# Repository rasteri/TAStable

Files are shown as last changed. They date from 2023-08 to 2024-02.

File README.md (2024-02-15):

# TAStable
Deliciously synchronizing the SNES' APU to its CPU clock

## Background
With few exceptions, Tool Assisted Speedruns are rigid lists of controller inputs that have no way to adapt to changing circumstances, and so require the game console to behave in a completely deterministic manner.

Many consoles - ones that drive their logic synchronously from a single master clock - behave more-or-less identically each time they are reset, and so are relatively simple to design speedruns for.

The SNES throws a spanner in the works by having its audio subsystem run from a separate clock. This secondary clock runs completely asynchronously to the main CPU clock, and in fact is derived from a very imprecise source (ceramic resonator). This plus a very non-deterministic reset circuit makes the SNES a difficult moving target for tool assisted speedruns to hit.

Workarounds such as latch trains have been found that increase reliability for certain games, but there are many others which just refuse to sync.

So we decided to just cheat and modify the console instead.

## Theory

NOTE - All of this applies to the 3chip snes (specifically the shvc-cpu-01 with SHVC-sound module) and may or may not be adaptable to other models.

### Terms - 
CPU - the main 65816 processor in the SNES

PPU1/PPU2 - the Picture Processing Units that generate graphics

APU - Audio Processing Unit, actually comprised of two processors - the SMP and DSP.

### Clock Domain Synchronizing

The SNES has two clock domains that are derived from two discrete non-synchronized oscillators. To have a hope of making the SNES deterministic, we have to derive these clocks from a common source.

Clock domain one is derived from a crystal and runs at 21.4773MHz (fraction 945/44). It directly clocks the CPU as well as PPU1 and PPU2.

Clock domain two is derived from a ceramic resonator and runs at 24.576MHz (29×48 kHz). It directly clocks the DSP, which in turn divides it by 12* and clocks the SMP.

*(During startup the DSP actually clocks the SMP at 1.024MHz for a while, presumably to synchronize the DSP and SMP’s memory read cycles, which we’ll go into later)

The ratio of the CPU clock to the APU clock is exactly 39375/45056, but that’s a little tricky to achieve in a low-cost FPGA. However a ratio of 7/8 is easier to implement and is close enough, in fact well within the tolerance of the ceramic resonator, so this ratio was decided upon.

Some simple FPGA code was written to generate a master 171.8184MHz clock. This is then divided by 7 to get a 24.55MHz APU clock, and divided by 8 to get a 21.4773MHz CPU clock.

Just deriving the clocks from a common source was good enough to make at least one game (Donkey Kong Country 2) “deterministic enough” to complete reliably - although it still required other workarounds (latch trains) to compensate for the remaining nondeterminism. Other games (Super Metroid) were still proving impossible to sync, so the decision was taken to track down every other source of nondeterminism come hell or high water.

### Reset Sequencing

The reset arrangement in the SNES looks like this : 

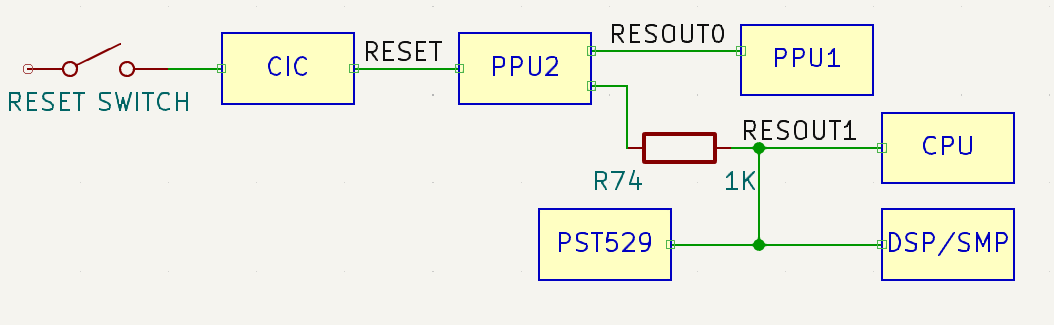
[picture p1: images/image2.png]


Net names are from the “snes_schematic_color.pdf” that’s floating around.

There are a number of ways the SNES can be reset. 

* Turning it on. The CIC will reset the PPU and the PST529 will reset the CPU/DSP/SMP. The PST529 takes a different amount of time to reset each time the SNES is switched on.
* Pressing the reset switch. The CIC will reset PPU2, which will in turn reset all the other components. As the CPU and APU’s resets are connected through a 1K resistor, this causes the signal to rise slowly and thus be susceptible to noise and other factors.
* Pull RESOUT1 low using external circuitry. This is often done to automate TAS playback, as the signal is accessible on the cartridge and expansion ports. This resets the CPU and DSP, but unfortunately doesn’t reset the PPU so leaves it in an unknown state.

None of these approaches allow the reset signal to trigger all ICs simultaneously. Luckily the solution is simple : 

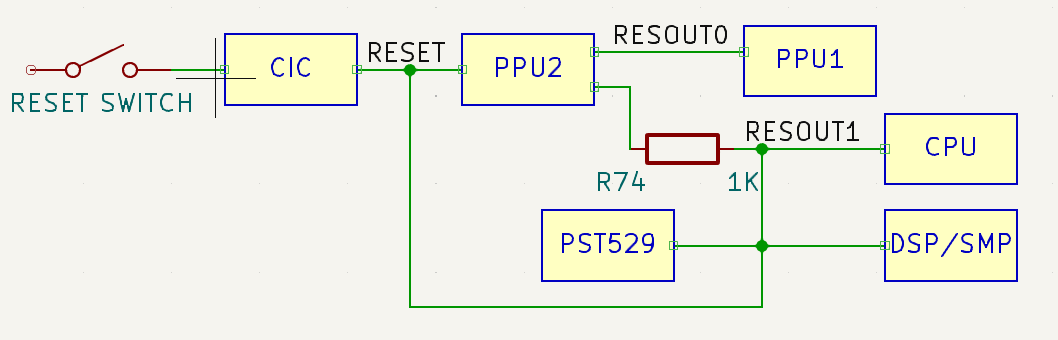
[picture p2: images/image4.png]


If RESOUT1 and RESET are connected together, all ICs are reset simultaneously (or at least, in a repeatable fashion).

There may be a better way to do this (maybe just shorting R74?)

### Reset Timing

This is still not enough to guarantee fully deterministic behavior, as with this setup we aren’t controlling the exact timing of the reset signal itself. Thus, the reset signal might happen at ANY point in the 21MHz/24MHz “synchronization cycle” - and there are infinite possibilities.

The “synchronization cycle” is equivalent to the beat frequency of the two clocks - i.e. 3MHz. So to ensure that the systems start up the same way each time, we have to ensure that the reset signal comes at the same point in the beat frequency on each reset.

To do this we can generate a third clock from the master 171.8184MHz clock, with a divider of 56, and reset the CPU/APU/PPUs on its rising (or falling) edge. As long as all three clocks are kept in the same phase, the reset signal will always happen at the same time in the clock sequence, and should guarantee determinism.

But, infuriatingly, even synchronizing the reset signal to the clock phase still doesn’t make the console 100% deterministic. It lowers the number of “different behaviour patterns” to about 20, so we know we’re going in the right direction, but there is still one more piece of the puzzle.

### Memory Bus Sniffing

The final piece of nondeterminism comes from the APU. As mentioned before, the DSP generates the SMP’s 2MHz clock by dividing the 24MHz clock. Unfortunately, the internal counters that the DSP uses to derive that clock are reset to a random state when the console powers up, and there is (probably?) no way to reset them back to zero. So, we need to find another way to determine where the APU is in its operation cycle.

When the APU starts up, it performs a number of read operations on its memory bus, followed by a memory write. After that point it appears to stabilize, i.e. it behaves deterministically. So if we can delay starting the CPU until after the first APU memory write, this will synchronize the two:

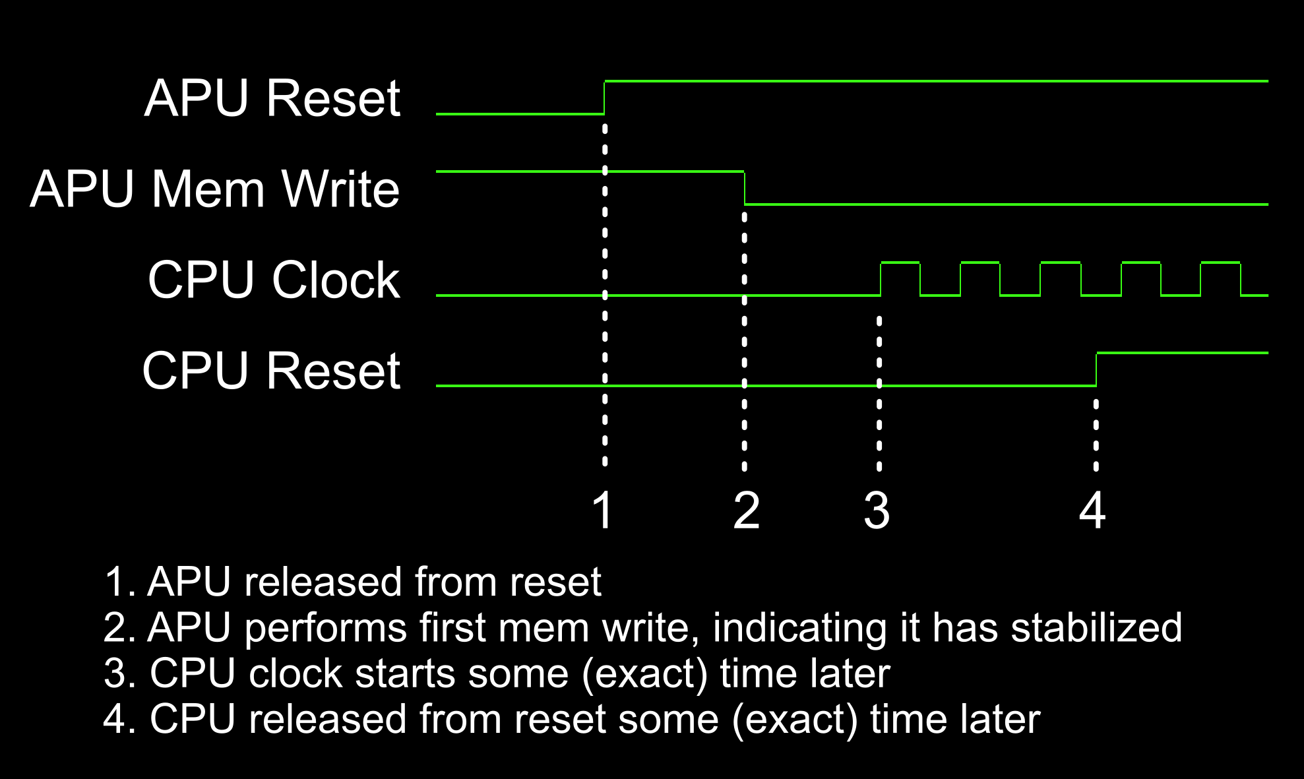
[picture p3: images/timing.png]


(Note, when it says “some (exact) time later”, this can be an arbitrary amount of time, but it should be carefully controlled to ensure it is reproducible. In addition, there appear to be certain values of time that do NOT result in deterministic behavior, presumably because it is too close to a clock transition or because it requires the clock to be high (or low) when the devices are brought out of reset.)

This requires separating the RESOUT1 signal into two sections, one for the CPU and one for the APU, and resetting them separately (APU first, then CPU after the APU stabilizes) :

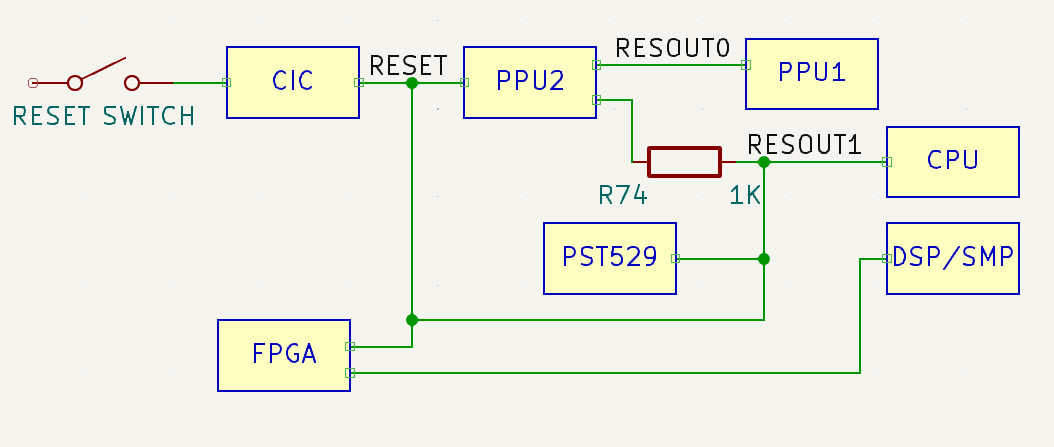
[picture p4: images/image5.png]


This approach still doesn't appear to make the snes fully deterministic, but that may be enough to sync runs that previously wouldn't.

More research will be done when I've finished moving house and I have access to my logic analyzer again

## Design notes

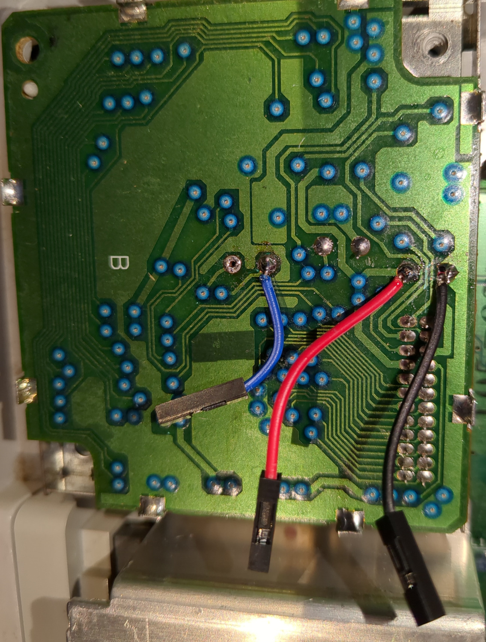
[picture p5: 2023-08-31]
images/2chip1.jpg

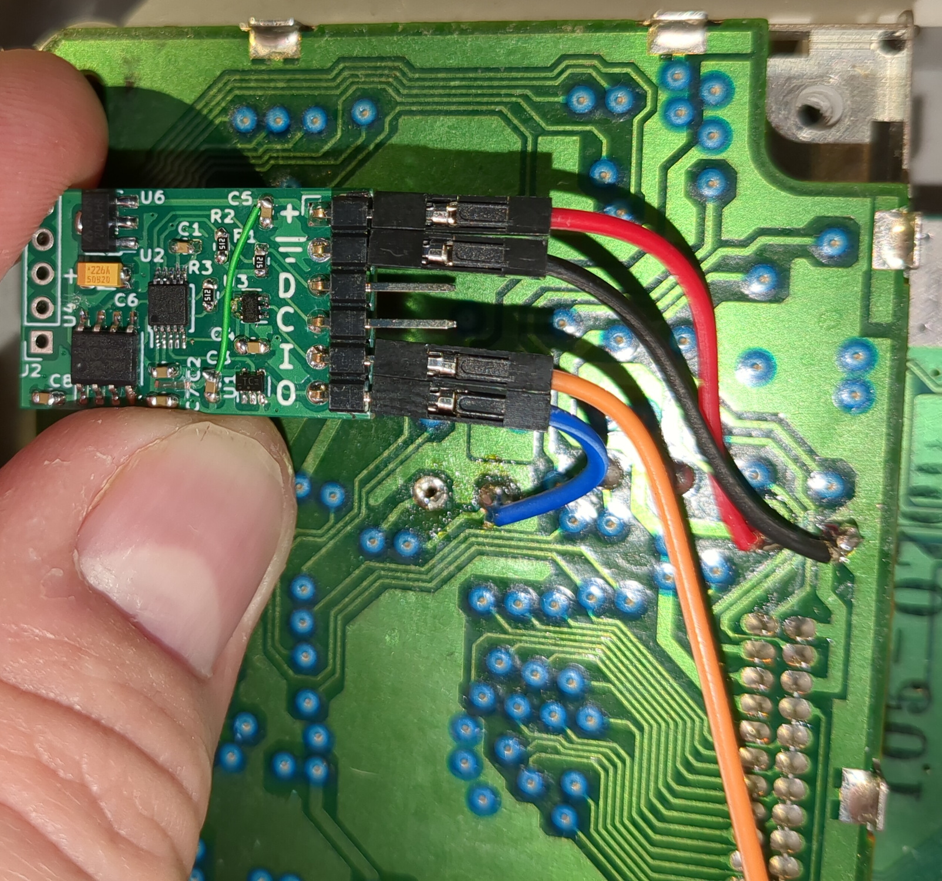
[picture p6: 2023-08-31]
images/2chip2.jpg

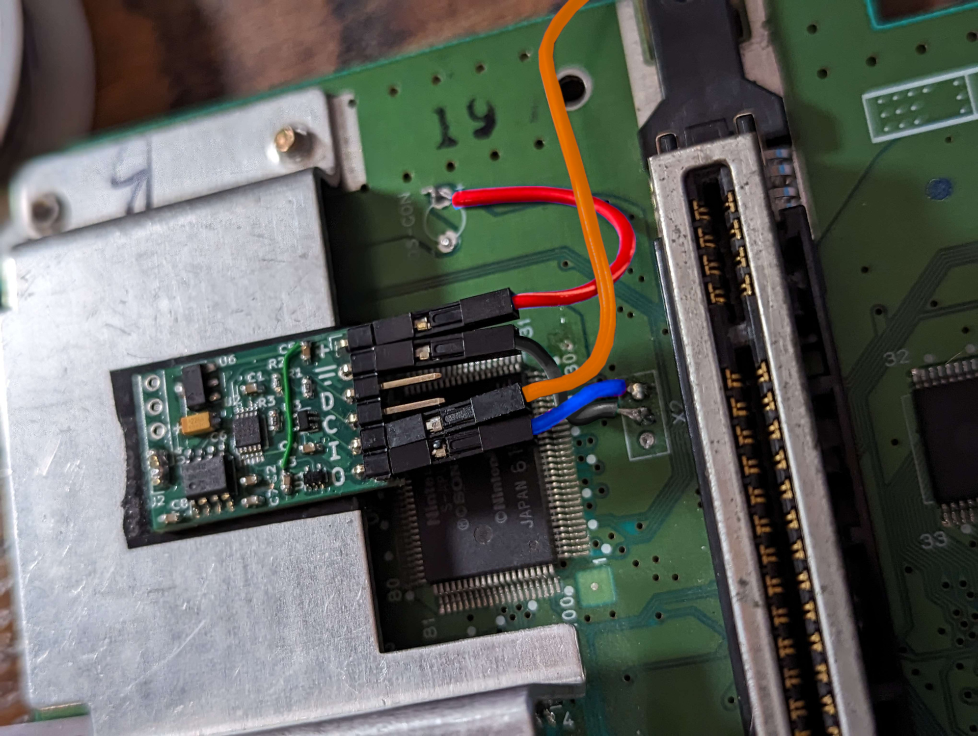
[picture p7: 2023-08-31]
images/1chip.jpg

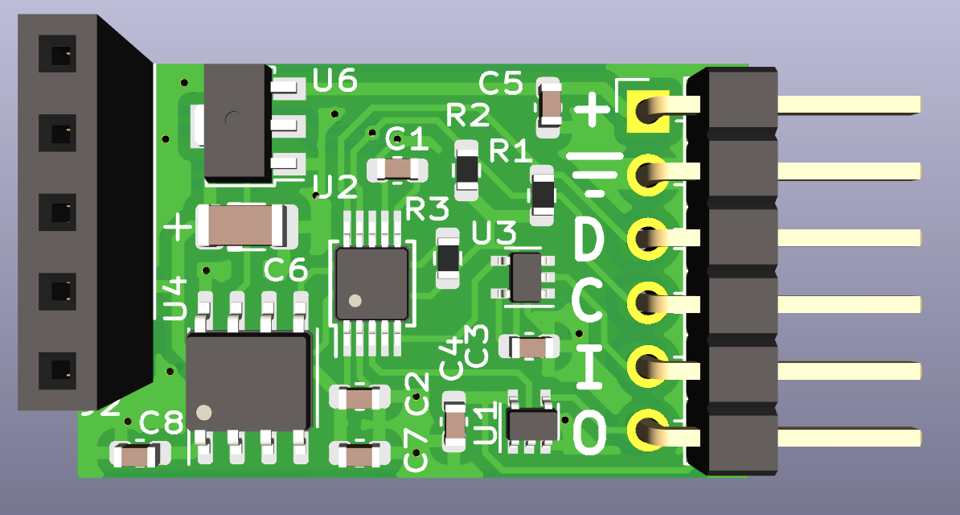
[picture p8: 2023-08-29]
images/board.png

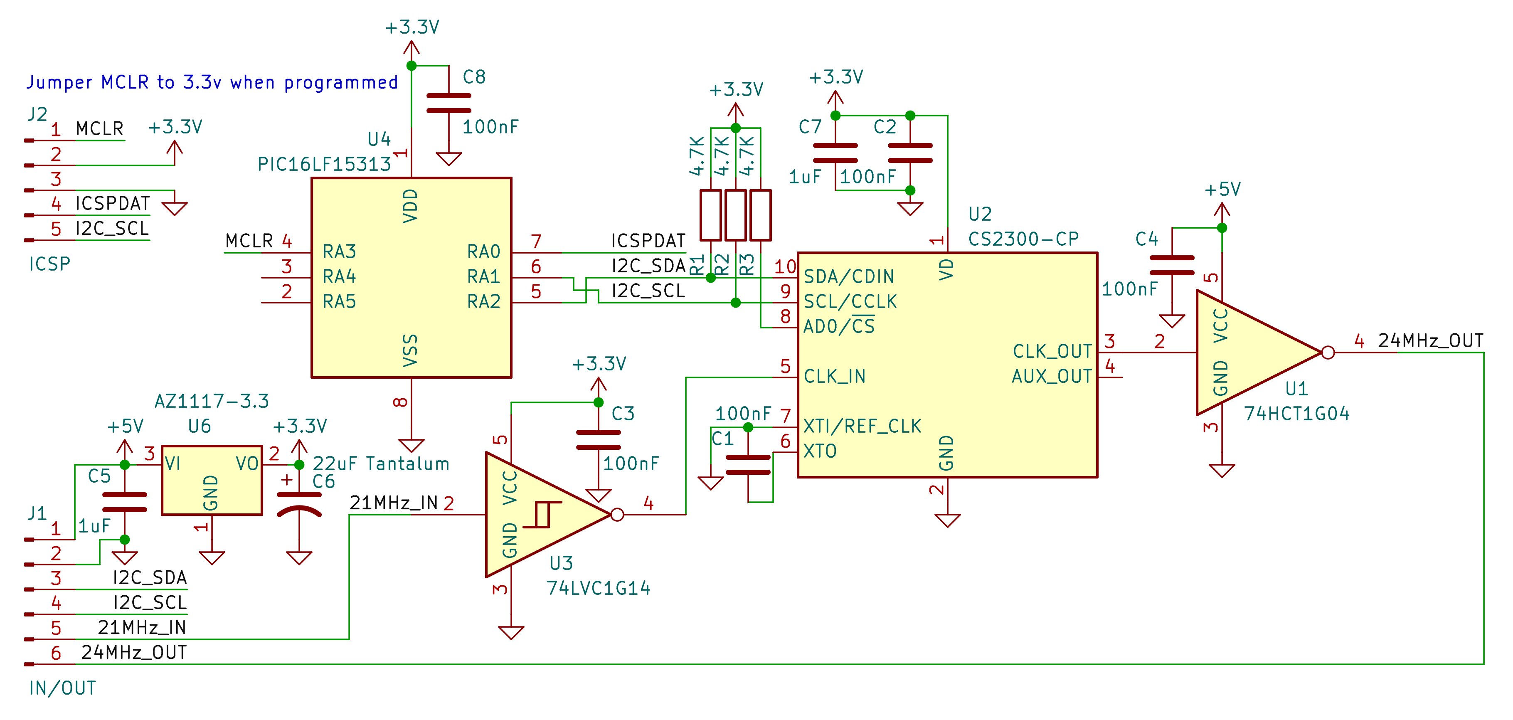
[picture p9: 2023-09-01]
images/schem.png

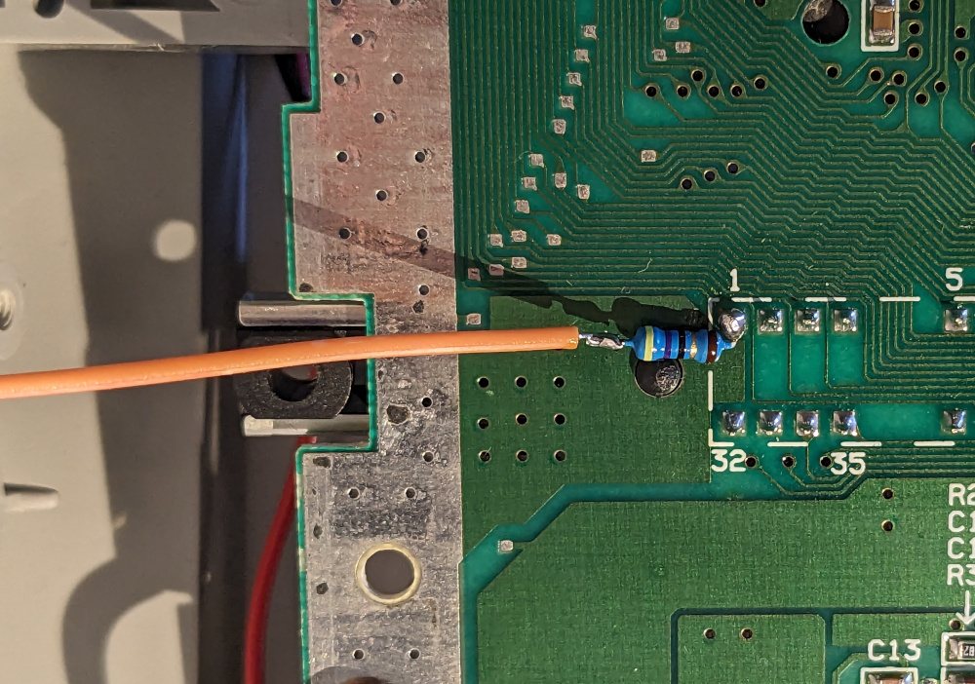
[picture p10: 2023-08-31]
images/in.jpg

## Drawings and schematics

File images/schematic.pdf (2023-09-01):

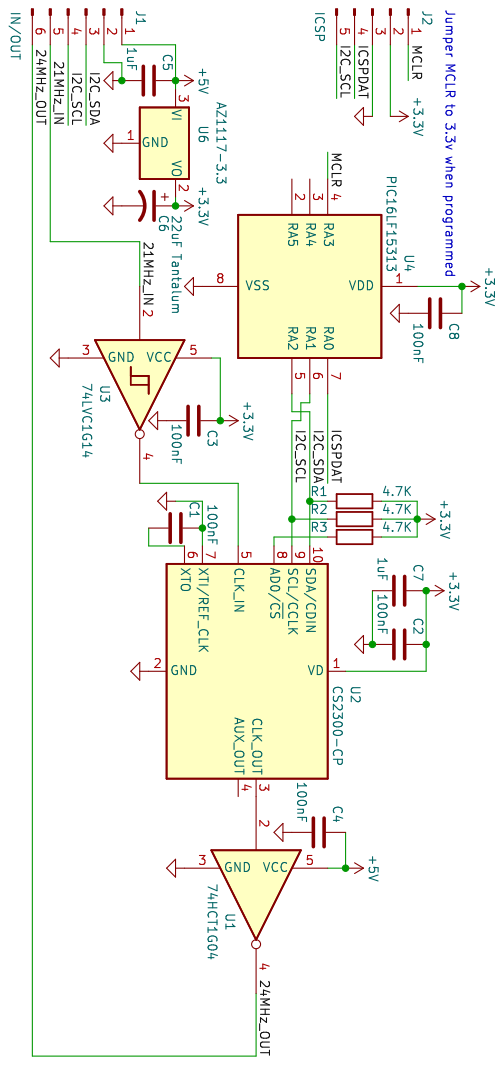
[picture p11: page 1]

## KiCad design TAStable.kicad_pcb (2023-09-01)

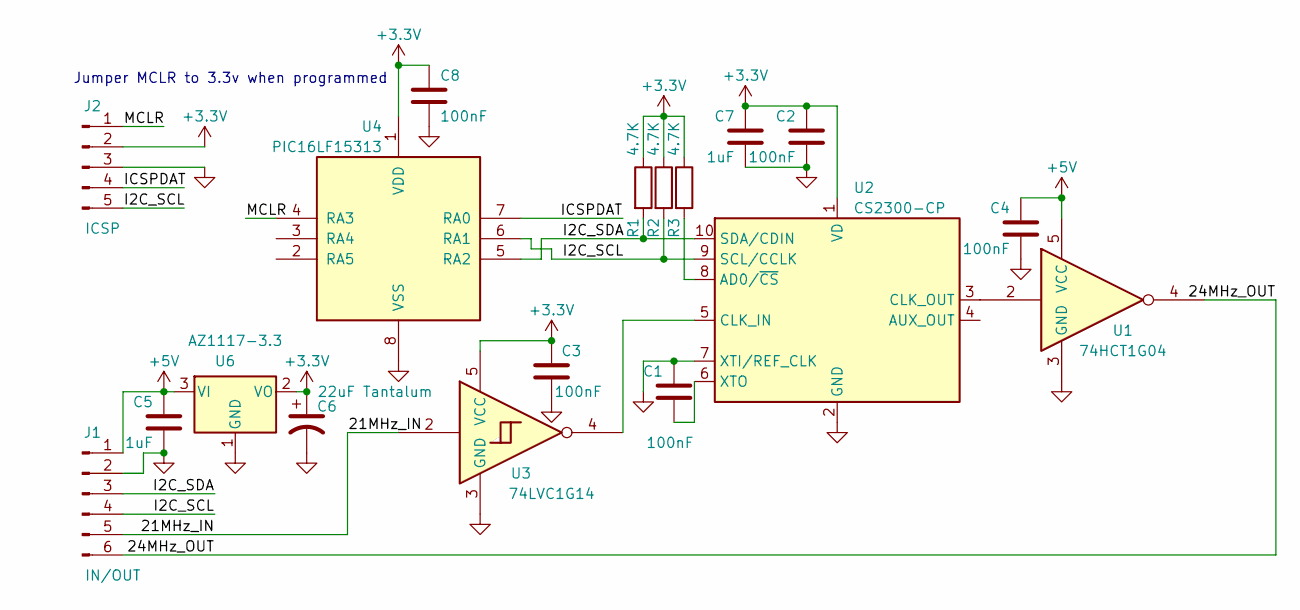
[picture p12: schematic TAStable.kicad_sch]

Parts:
C1, C2, C3, C4, C8: 100nF; C_0603_1608Metric
C5, C7: 1uF; C_0603_1608Metric
C6: 22uF Tantalum; C_1206_3216Metric
J1: IN/OUT; PinHeader_1x06_P2.54mm_Horizontal
J2: ICSP; PinSocket_1x05_P2.54mm_Vertical
R1, R2, R3: 4.7K; R_0603_1608Metric
U1: 74HCT1G04; SOT-353_SC-70-5
U2: CS2300-CP; MSOP-10_3x3mm_P0.5mm
U3: 74LVC1G14; SOT-353_SC-70-5
U4: PIC16LF15313; SOIC-8_3.9x4.9mm_P1.27mm
U6: AZ1117-3.3; SOT-89-3

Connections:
+3.3V: C2.1, C3.1, C6.1, C7.1, C8.1, J2.2, R1.1, R2.1, R3.1, U2.1 (VD), U3.5 (VCC), U4.1 (VDD), U6.2 (VO)
+5V: C4.1, C5.1, J1.1, U1.5 (VCC), U6.3 (VI)
/21MHz_IN: J1.5, U3.2
/24MHz_OUT: J1.6, U1.4
/I2C_SCL: J1.4, J2.5, R2.2, U2.9 (SCL/CCLK), U4.6 (RA1)
/I2C_SDA: J1.3, R1.2, U2.10 (SDA/CDIN), U4.5 (RA2)
/ICSPDAT: J2.4, U4.7 (RA0)
/MCLR: J2.1, U4.4 (RA3)
GND: C1.1, C2.2, C3.2, C4.2, C5.2, C6.2, C7.2, C8.2, J1.2, J2.3, U1.3 (GND), U2.2 (GND), U2.7 (XTI/REF_CLK), U3.3 (GND), U4.8 (VSS), U6.1 (GND)
unnamed: R3.2, U2.8 (AD0/~CS)
unnamed: U2.5 (CLK_IN), U3.4
unnamed: U1.2, U2.3 (CLK_OUT)
unnamed: C1.2, U2.6 (XTO)

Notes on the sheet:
Jumper MCLR to 3.3v when programmed

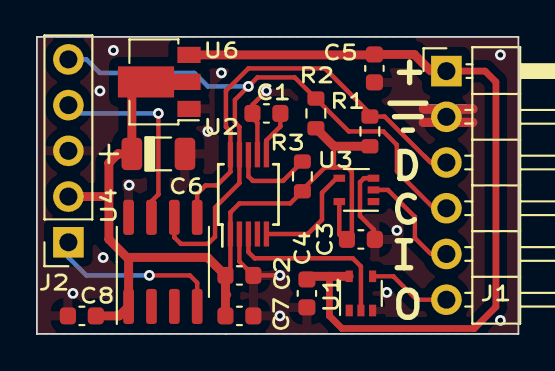
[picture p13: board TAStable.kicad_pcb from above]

Board: 2 copper layers, 26.8 x 16.5 mm, 18 parts (0 on the bottom side), 13 nets.

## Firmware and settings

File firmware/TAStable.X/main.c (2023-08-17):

/**
  Generated Main Source File

  Company:
    Microchip Technology Inc.

  File Name:
    main.c

  Summary:
    This is the main file generated using PIC10 / PIC12 / PIC16 / PIC18 MCUs

  Description:
    This header file provides implementations for driver APIs for all modules selected in the GUI.
    Generation Information :
        Product Revision  :  PIC10 / PIC12 / PIC16 / PIC18 MCUs - 1.81.8
        Device            :  PIC16F18313
        Driver Version    :  2.00
*/

/*
    (c) 2018 Microchip Technology Inc. and its subsidiaries. 
    
    Subject to your compliance with these terms, you may use Microchip software and any 
    derivatives exclusively with Microchip products. It is your responsibility to comply with third party 
    license terms applicable to your use of third party software (including open source software) that 
    may accompany Microchip software.
    
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
    IN NO EVENT WILL MICROCHIP BE LIABLE FOR ANY INDIRECT, SPECIAL, PUNITIVE, 
    INCIDENTAL OR CONSEQUENTIAL LOSS, DAMAGE, COST OR EXPENSE OF ANY KIND 
    WHATSOEVER RELATED TO THE SOFTWARE, HOWEVER CAUSED, EVEN IF MICROCHIP 
    HAS BEEN ADVISED OF THE POSSIBILITY OR THE DAMAGES ARE FORESEEABLE. TO 
    THE FULLEST EXTENT ALLOWED BY LAW, MICROCHIP'S TOTAL LIABILITY ON ALL 
    CLAIMS IN ANY WAY RELATED TO THIS SOFTWARE WILL NOT EXCEED THE AMOUNT 
    OF FEES, IF ANY, THAT YOU HAVE PAID DIRECTLY TO MICROCHIP FOR THIS 
    SOFTWARE.
*/

#include "mcc_generated_files/mcc.h"
#include "mcc_generated_files/examples/i2c1_master_example.h"

void I2C_Slave_Init(short address) {
    SSPSTAT = 0b10000000;
    SSPADD = address; //Setting address
    SSPCON1 = 0b00110110; // Enabled, No clock stretching, I2C Slave, 7bit address
    SSPCON2 = 0x01;


    SSP1IF = 0; // Clear the serial port interrupt flag
    BCL1IF = 0; // Clear the bus collision interrupt flag
    BCL1IE = 1; // Enable bus collision interrupts
    SSP1IE = 1; // Enable serial port interrupts
    PEIE = 1; // Enable peripheral interrupts
    GIE = 1; // Enable global interrupts
}

unsigned int index_i2c = 0; // used as an index pointer in array
unsigned char junk = 0; // used to place unnecessary data
unsigned char first = 1; // used to determine whether data address 

void __interrupt () ISR(void) {
    if (SSP1IF) // check to see if SSP interrupt
    {
        if (SSPSTATbits.R_nW) { // Master read (R_nW = 1)
            junk = SSPBUF;
            SSPBUF = 0x96;//DATAEE_ReadByte(0xF000 + index_i2c);
            SSPCON1bits.CKP = 1; // Release CLK
        }
        if (!SSPSTATbits.R_nW) { //  Master write (R_nW = 0)

            if (!SSPSTATbits.D_nA) { // Last byte was an address (D_nA = 0)
                first = 1; //last byte was address, next will be data location
                junk = SSPBUF; // read buffer to clear BF
                SSPCON1bits.CKP = 1; // Release CLK
            }
            if (SSPSTATbits.D_nA) // Last byte was data (D_nA = 1)
            {
                if (first) {
                    index_i2c = SSPBUF; // load index with array location
                    first = 0; // now clear this
                } else {
                    junk = SSPBUF; // Master did two data writes
                    
                    //3137 means reset
                    if (index_i2c == 0x31 && junk == 0x37) 
                        RESET();
                    
                    DATAEE_WriteByte(0xF000 + index_i2c, junk);
                    
                }

                if (SSPCON1bits.WCOL) { // Did a write collision occur?

                    SSPCON1bits.WCOL = 0; //  clear WCOL
                    junk = SSPBUF; // dummy read to clear BF bit
                }
                SSPCON1bits.CKP = 1; // Release CLK
            }
        }
    }
    if (BCL1IF) // Did a bus collision occur?
    {

        junk = SSPBUF; // dummy read SSPBUF to clear BF bit
        BCL1IF = 0; // clear bus collision Int Flag bit
        SSPCON1bits.CKP = 1; // Release CLK
    }
    SSP1IF = 0; // clear SSPIF flag bit
}

static uint8_t VALIDREGS[] = {0x02, 0x03, 0x05, 0x06, 0x07, 0x08, 0x09, 0x16, 0x17, 0x1E};

static uint8_t DEFAULTCFG[] = 
{
    0x00,                       // 00 not used
    0x00,                       // 01
    0x00,                       // 02 - aux/clock out disables
    0x05,                       // 03 - Device CFG 1
    0x00,                       // 04
    0x01,                       // 05 - global cfg
    0x00, 0x12, 0x4F, 0x1C,     // 06:09 - 32-bit ratio
    0x00, 0x00, 0x00, 0x00,     // 0A:0D
    0x00, 0x00, 0x00, 0x00,     // 0E:11
    0x00, 0x00, 0x00, 0x00,     // 12:15
    0x11,                       // 16 - funct cfg 1
    0x08,                       // 17 - funct cfg 2
    0x00, 0x00, 0x00, 0x00,     // 18:1B
    0x00, 0x00,                 // 1C:1D
    0x00,                       // 1E - funct cfg 3
    0x00,                       // 1F
    0x54, 0x17, 0x80, 0x08      // 20:23 magic value
};

    /*
    i2cset -y 1 0x4F 0x03 0x05
    i2cset -y 1 0x4F 0x05 0x01
    i2cset -y 1 0x4F 0x06 0x00
    i2cset -y 1 0x4F 0x07 0x12
    i2cset -y 1 0x4F 0x08 0x4F
    i2cset -y 1 0x4F 0x09 0x1C
    i2cset -y 1 0x4F 0x16 0x11
    i2cset -y 1 0x4F 0x17 0x08
    i2cset -y 1 0x4f 0x1E 0x00
    */


/*
                         Main application
 */
void main(void)
{
    uint8_t i;
    
    // initialize the device
    SYSTEM_Initialize();

    // When using interrupts, you need to set the Global and Peripheral Interrupt Enable bits
    // Use the following macros to:



    // Disable the Global Interrupts
    //INTERRUPT_GlobalInterruptDisable();

    // Disable the Peripheral Interrupts
    //INTERRUPT_PeripheralInterruptDisable();

    // check if eeprom is valid
    if (
            DATAEE_ReadByte(0xF020) != 0x54 ||
            DATAEE_ReadByte(0xF021) != 0x17 ||
            DATAEE_ReadByte(0xF022) != 0x80 ||
            DATAEE_ReadByte(0xF023) != 0x08
            )
    {
        // if not, make it valid from default values
        for (i = 0; i < sizeof(DEFAULTCFG); i++){
            DATAEE_WriteByte(0xF000 + i, DEFAULTCFG[i]);
        }
    }
    
    // write the registers from EEPROM to the CS2300
    for (i = 0; i < sizeof(VALIDREGS); i++ ){
        I2C1_Write1ByteRegister(0x4F, VALIDREGS[i], DATAEE_ReadByte(0xF000 + VALIDREGS[i]));
    }
    
    /*I2C1_Write1ByteRegister(0x4F, 0x03, 0x05);
    I2C1_Write1ByteRegister(0x4F, 0x05, 0x01);
    I2C1_Write1ByteRegister(0x4F, 0x06, 0x00);
    I2C1_Write1ByteRegister(0x4F, 0x07, 0x12);
    I2C1_Write1ByteRegister(0x4F, 0x08, 0x4F);
    I2C1_Write1ByteRegister(0x4F, 0x09, 0x1C);
    I2C1_Write1ByteRegister(0x4F, 0x16, 0x11);
    I2C1_Write1ByteRegister(0x4F, 0x17, 0x08);
    I2C1_Write1ByteRegister(0x4f, 0x1E, 0x00);*/
    
    //now switch to I2C slave mode to allow EEPROM reprogramming
    I2C_Slave_Init(0xD2);
    
    while (1)
    {
        
        
        // Add your application code
    }
}
/**
 End of File
*/

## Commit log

2023-07-10 added board img
2023-08-17 5v output buffer
    [TAStable.kicad_pcb, TAStable.kicad_sch]
2023-08-17 i2c slave updates
2023-08-29 Board pic
    [TAStable.kicad_pcb]
2023-08-31 more pics + cleanups
    [TAStable.kicad_pcb, TAStable.kicad_sch]
